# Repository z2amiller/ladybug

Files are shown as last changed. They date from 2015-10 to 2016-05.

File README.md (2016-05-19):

# ladybug
attiny85 + WS2812 replacement for CloudB ladybug nightlight.

## Installation
Album showing disassembly [here](http://imgur.com/a/Ccf88).

The ladybug has six screws that hold the shell on.  They're
under the fabric.  I had to cut a small slit in the fabric to
access some of them, others I was able to get at through
the hole for the battery pack.

## Programming

The ladybug can be programmed in-system with an 8 pin SOIC clip
like [this](http://www.amazon.com/dp/B015W4PKR6).  I have used
a [small programming shield](http://www.electrodragon.com/product/attiny-1385-programming-shield/)
plus an Arduino UNO as the programmer.   You could also make
a custom cable to hook onto a dedicated programmer like the
[USBASP](http://www.electrodragon.com/product/8051-avr-mcu-programmer-usbasp/)
programmer.

## Future work

It turns out that the WS2812b LEDs (aka Neopixels) have quite a high
quiescent current - around 800uA.  This ends up eating batteries
moderately quickly.

One idea would be to connect the wakeup button to a
[soft latching circuit](http://electronics.stackexchange.com/questions/4060/make-a-momentary-switch-control-a-toggle)
and use the output of the toggle control the enable pin of a power
regulator end connect the current WAKE pin on the attiny85 as a
second momentary input to turn it off after 30 minutes.

For example, that circuit controlling the enable pin of a 5V boost
regulator would make the following improvements:

* Vastly reduced quiescent current, probably under 20ua.  Only the
  latch would be consuming measureable power.
* Simplified programming, less need for fancy interrupt and sleep
  routines - at the end of the cycle, the attiny85 would just
  poke the toggle and turn the power off.
* Better performance with low batteries.  Right now, as the batteries
  decay, the ladybug gets wonky.  The blue LED has a higher forward
  voltage, so as the batteries start to run down, the blue LED inside
  the WS2818b will no longer light up, though the green and red channels
  continue to work.
* Probably a little bit brighter running at full 5v instead of the 4.5v
  or less coming from 3xAAA batteries.

There is plenty of room on the board for a boost regulator and toggle circuit.

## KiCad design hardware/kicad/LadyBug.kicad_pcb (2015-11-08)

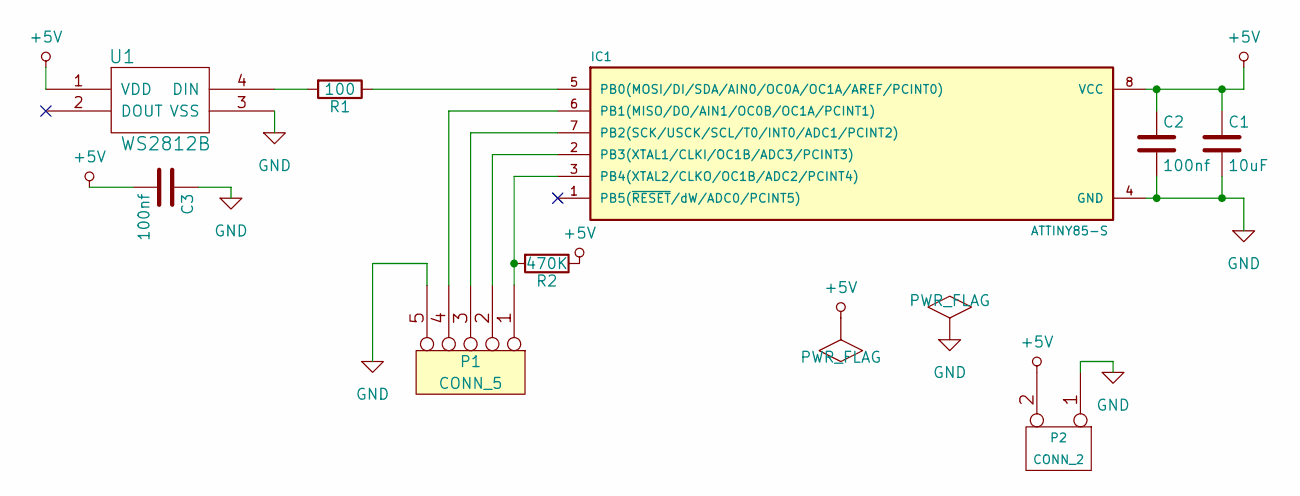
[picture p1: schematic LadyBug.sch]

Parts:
C1: 10uF; C_0805_HandSoldering
C2, C3: 100nf; C_0603_HandSoldering
IC1: ATTINY85-S; so-8
P1: CONN_5; Pin_Header_Straight_1x05
P2: CONN_2; Pin_Header_Straight_1x02
R1: 100; R_0603_HandSoldering
R2: 470K; R_0603_HandSoldering
U1: WS2812B; Pin_Header_Straight_1x04

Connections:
+5V: C1.1, C2.1, C3.2, IC1.8 (VCC), P2.2 (PM), R2.1, U1.1 (VDD)
GND: C1.2, C2.2, C3.1, IC1.4 (GND), P1.5, P2.1, U1.3 (VSS)
unnamed: IC1.2 (PB3(XTAL1/CLKI/OC1B/ADC3/PCINT3)), P1.2
unnamed: IC1.3 (PB4(XTAL2/CLKO/OC1B/ADC2/PCINT4)), P1.1, R2.2
unnamed: IC1.5 (PB0(MOSI/DI/SDA/AIN0/OC0A/OC1A/AREF/PCI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), R1.1
unnamed: IC1.6 (PB1(MISO/DO/AIN1/OC0B/OC1A/PCINT1)), P1.4
unnamed: IC1.7 (PB2(SCK/USCK/SCL/T0/INT0/ADC1/PCINT2)), P1.3
unnamed: R1.2, U1.4 (DIN)

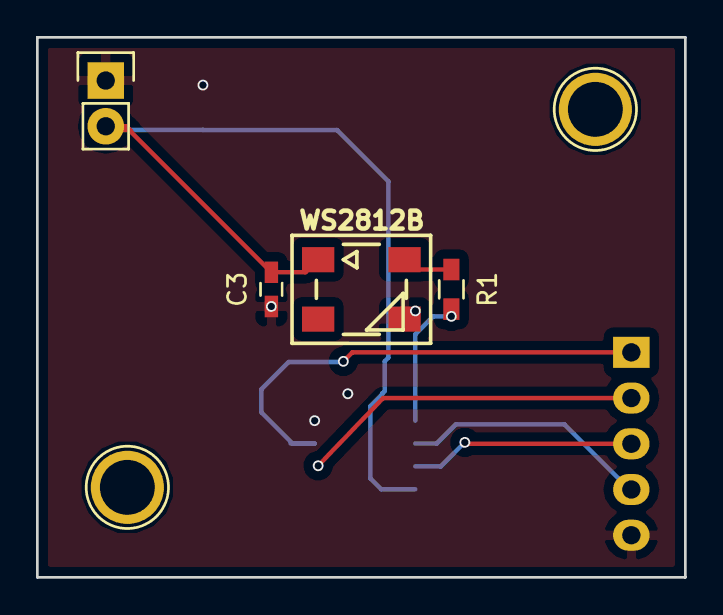
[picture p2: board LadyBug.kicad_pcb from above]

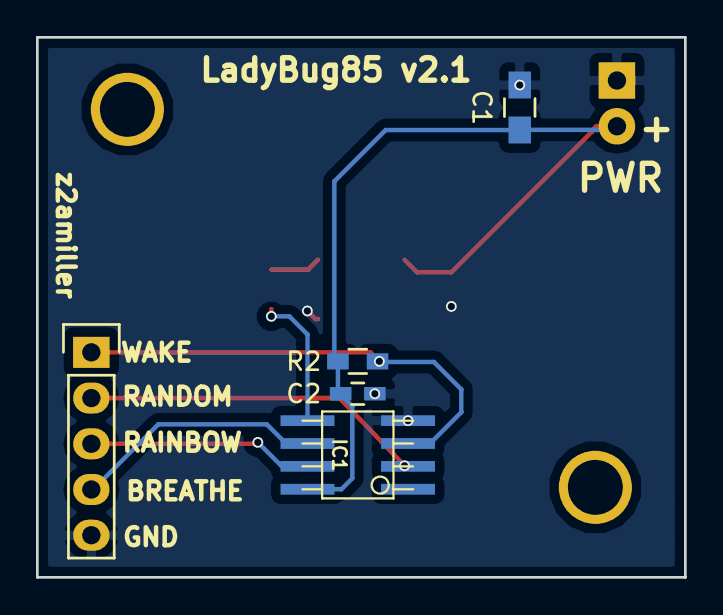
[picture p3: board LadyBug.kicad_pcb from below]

Board: 2 copper layers, 36.0 x 30.0 mm, 9 parts (5 on the bottom side), 8 nets.

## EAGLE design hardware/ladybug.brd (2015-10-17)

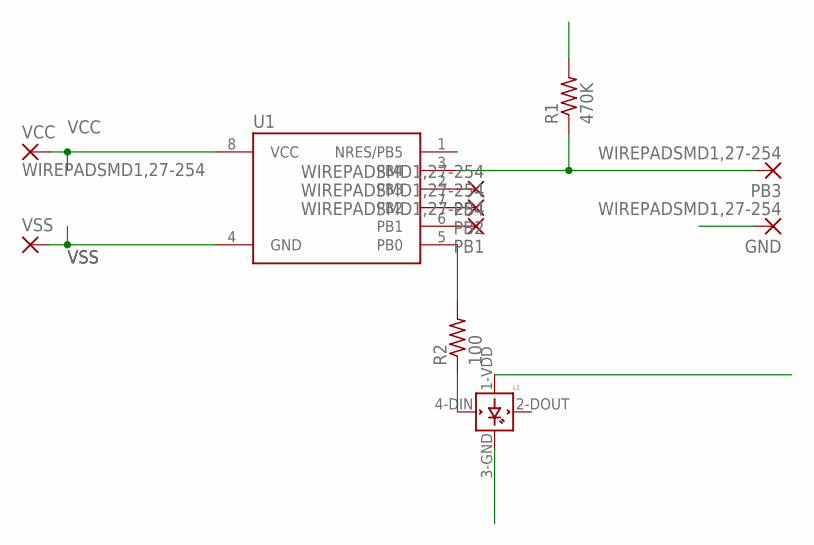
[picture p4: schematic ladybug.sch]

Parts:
GND: WIREPADSMD1,27-254; SMD1,27-2,54
L1: WS2812B
PB1, PB2, PB3, PB4: WIREPADSMD1,27-254; SMD1,27-2,54
R1: 470K; M1206
R2: 100; M1206
U1: ATTINY85-20S; SOIC8_EIAJ_208MIL
VCC: WIREPADSMD1,27-254; SMD1,27-2,54
VSS: WIREPADSMD1,27-254; SMD1,27-2,54

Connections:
unnamed: R2.2, U1.5 (PB0)
unnamed: L1.4-DIN (DIN), R2.1
unnamed: PB4.1, U1.2 (PB3)
unnamed: PB1.1, U1.6 (PB1)
unnamed: PB2.1, U1.7 (PB2)
PB3: PB3.1, R1.1, U1.3 (PB4)
VCC: L1.1-VDD (VDD), R1.2, U1.8 (VCC), VCC.1
VSS: GND.1, L1.3-GND (GND), U1.4 (GND), VSS.1

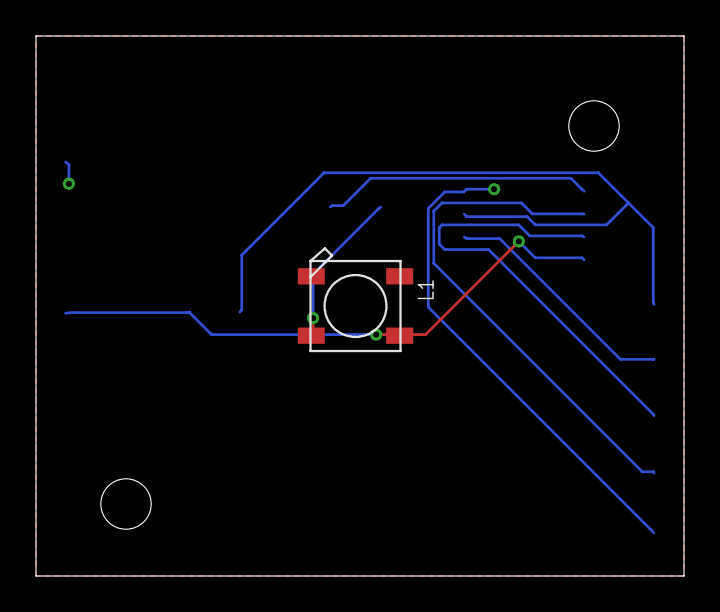
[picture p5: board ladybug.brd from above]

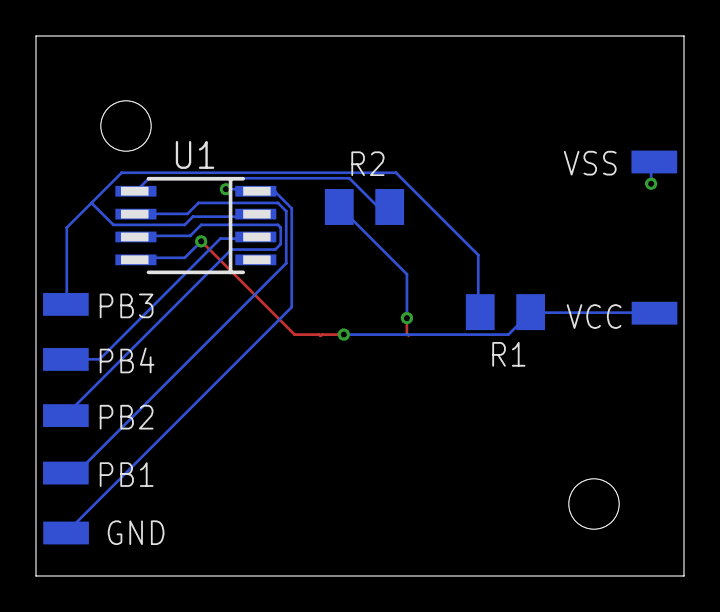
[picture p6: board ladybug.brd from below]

Board: 2 copper layers, 36.0 x 30.0 mm, 11 parts (10 on the bottom side), 8 nets.

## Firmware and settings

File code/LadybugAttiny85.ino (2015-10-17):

#include <LadybugActions.h>
#include <Bounce2.h>
#include <Adafruit_NeoPixel.h>
#include <avr/sleep.h>

#ifndef cbi
#define cbi(sfr, bit) (_SFR_BYTE(sfr) &= ~_BV(bit))
#endif
#ifndef sbi
#define sbi(sfr, bit) (_SFR_BYTE(sfr) |= _BV(bit))
#endif

enum color_mode {
  MODE_RAINBOW,
  MODE_BREATHE,
  MODE_RANDOM
};

#define LED_PIN 0
#define RANDOM_PIN 4
#define WAKEUP_PIN 3
#define RAINBOW_PIN 2
#define BREATHE_PIN 1

Adafruit_NeoPixel strip = Adafruit_NeoPixel(1, LED_PIN, NEO_GRB + NEO_KHZ800);
const long on_time = 35 * 60 * 1000L;
volatile long last_stop = 0L;
color_mode mode = MODE_RAINBOW;

Bounce rainbow_switch = Bounce();
Bounce breathe_switch = Bounce();
Bounce random_switch = Bounce();

Rainbow rainbow = Rainbow(&strip, 5000);
Breather breathe = Breather(&strip, 30);
FadeCycler randomizer = FadeCycler(&strip, 5000, 10);

ISR(PCINT0_vect) {
  last_stop = millis();
}

void powerDown () {
  cbi(ADCSRA, ADEN); // Turn off ADC
  set_sleep_mode(SLEEP_MODE_PWR_DOWN);
  sleep_bod_disable();
  sleep_mode();
  sbi(ADCSRA, ADEN); // Turn on ADC
}

void shutDown() {
  strip.setPixelColor(0, 0);
  strip.show();
  sbi(GIMSK, PCIE);  // Turn on Pin Change interrupt
  sbi(PCMSK, PCINT3); // Which pins are affected by the interru                                                                                                                                                                                                                                                                                                                                                                                                                                                                                                                                                                                                                                                                                                                                   pt
  powerDown();
  cbi(GIMSK, PCIE);  // Turn on Pin Change interrupt
  cbi(PCMSK, PCINT3); // Which pins are affected by the interrupt
}

void setup() {
  pinMode(WAKEUP_PIN, INPUT_PULLUP);
  pinMode(RAINBOW_PIN, INPUT_PULLUP);
  pinMode(BREATHE_PIN, INPUT_PULLUP);
  pinMode(RANDOM_PIN, INPUT_PULLUP);
  rainbow_switch.attach(RAINBOW_PIN);
  rainbow_switch.interval(75);
  breathe_switch.attach(BREATHE_PIN);
  breathe_switch.interval(75);
  random_switch.attach(RANDOM_PIN);
  random_switch.interval(75);

  strip.begin();
  strip.setBrightness(255);
  sei();             // Enable interrupts.
  shutDown();        // Start in powered-off state, ready to be woken by power button.
}

void loop() {
  if (last_stop + on_time <= millis()) {
    shutDown();
  }
  rainbow_switch.update();
  breathe_switch.update();
  random_switch.update();
  // Debouncing this is a little more complicated because it is also the wakeup pin.
  if (digitalRead(WAKEUP_PIN) == LOW) {
    if (last_stop + 1000 <= millis()) {
      while (digitalRead(WAKEUP_PIN) == LOW)
        delay(25);
      shutDown();
    }
  }
  if (rainbow_switch.read() == LOW) {
    last_stop = millis();
    mode = MODE_RAINBOW;
  }
  if (breathe_switch.read() == LOW) {
    breathe.cycle();
    last_stop = millis();
    mode = MODE_BREATHE;
  }
  if (random_switch.read() == LOW) {
    randomSeed(micros());
    last_stop = millis();
    mode = MODE_RANDOM;
  }
  switch (mode) {
    case MODE_RAINBOW:
      rainbow.update();
      break;
    case MODE_BREATHE:
      breathe.update();
      break;
    case MODE_RANDOM:
      randomizer.update();
      break;
  }

}

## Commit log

2015-10-17 Add the ladybug arduino files.
2015-10-17 Add eagle files for the ladybug.
    [ladybug.brd, ladybug.sch]
2015-10-25 Kicad version of ladybug hardware.
    [LadyBug.kicad_pcb, LadyBug.sch]
2015-10-25 Add the plotted gerber files.
    [LadyBug-B_Cu.gbr, LadyBug-B_Mask.gbr, LadyBug-B_SilkS.gbr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]
2015-10-25 Oops, swapped front and back.
    [LadyBug.kicad_pcb]
2015-10-25 Moved some silscreens around.
    [LadyBug.kicad_pcb]
2015-10-25 Removed extra gerber zip.
2015-10-25 New gerbers, off to OshPark
    [LadyBug-B_Cu.gbr, LadyBug-B_Mask.gbr, LadyBug-B_SilkS.gbr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]
2015-11-08 Some ladybug tweaking, v1 of board DOA.
    [LadyBug-B.Cu.gbl, LadyBug-B.Mask.gbs, LadyBug-B.SilkS.gbo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]
2015-11-08 Added some more silkscreening.
    [LadyBug.kicad_pcb]
2015-11-08 Changed silkscreen to match version 2.1.
    [LadyBug.kicad_pcb]
2015-11-08 Add gerber files - off to OshPark again.
    [LadyBug-B.Cu.gbl, LadyBug-B.Mask.gbs, LadyBug-B.SilkS.gbo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]
